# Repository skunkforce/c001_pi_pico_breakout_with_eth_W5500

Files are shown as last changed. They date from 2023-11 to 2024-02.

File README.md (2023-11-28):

# edgy_board number c001
This design is part of the [edgy board project](https://github.com/skunkforce/edgy_boards).

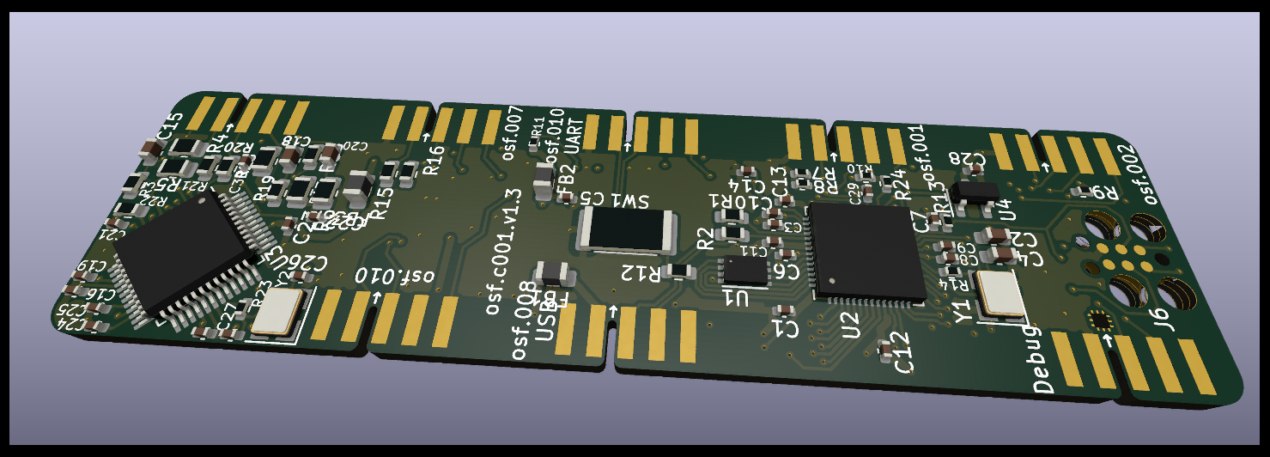
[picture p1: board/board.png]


This design is a composition of edgies.
```mermaid
graph LR
    b018(b018 RP2040)-- SPI -->b078(b078 Ethernet MAC+PHY)
    b018--> b096(b096 MAC ID)

```
# getting started
This repository uses submodules. After cloning use the command 

```$ git submodule update --init --recursive```

to pull the submodules before opening the project with kicad. 

# Tests
Tests can be found in [TESTS.md](TESTS.md)

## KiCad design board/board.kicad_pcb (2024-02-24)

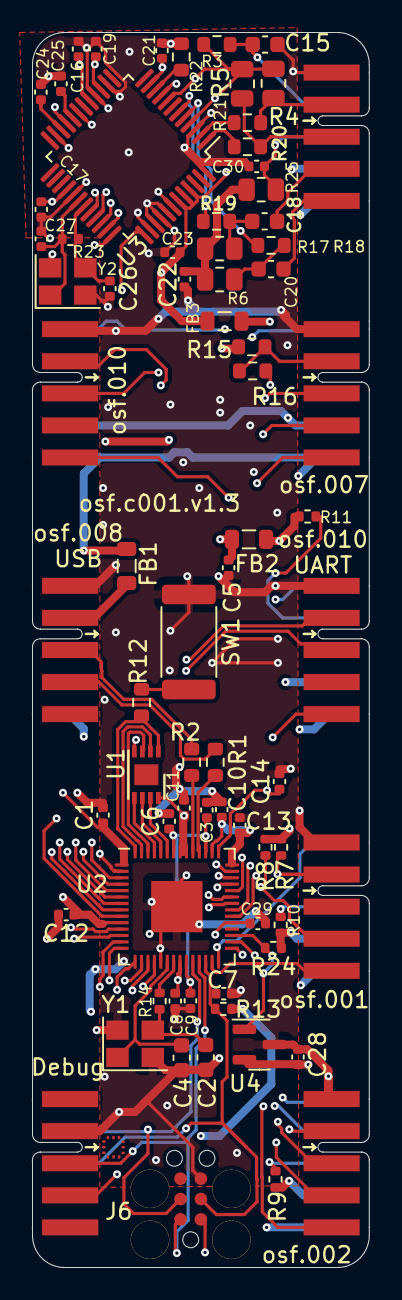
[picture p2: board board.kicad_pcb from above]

Board: 4 copper layers, 21.0 x 77.0 mm, 75 parts (1 on the bottom side), 76 nets.

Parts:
C1, C3, C5, C6, C8, C10, C11, C12, C16, C17, C19, C21, C23, C28, C29, C30: 100nF; C_0402_1005Metric
C2, C4: 12pF; C_0603_1608Metric
C7: 1uF; C_0402_1005Metric
C9, C13, C14: 2.2uF; C_0402_1005Metric
C15: 22nF; C_0603_1608Metric
C18, C20: 6.8nF; C_0603_1608Metric
C22, C24: 10nF; C_0402_1005Metric
C25: 4.7uF; C_0402_1005Metric
C26, C27: 18pF; C_0402_1005Metric
FB1: Ferrite_Bead_Small; L_0805_2012Metric
FB2, FB3: FerriteBead_Small; L_0805_2012Metric
J1: UART; on_edge_2x05_device
J2: 008_USB; on_edge_2x05_device
J3: DebugEdge_02x05; debug_edge_2x05_device
J4: 019_100BASE-T_with_CT; on_edge_2x05_host
J5: ADC_2x3; on_edge_2x05_host
J6: SWD_6_Pol_Needle; SWD6pol
J7: SPI_2x3; on_edge_2x05_host
J8: I2C_2x2; on_edge_2x05_host
J9: UART_2x2; on_edge_2x05_host
LOGO1: Logo_Open_Hardware_Small; OSHW-Symbol_6.7x6mm_SilkScreen
R1, R2: 27R; R_0603_1608Metric
R3: 10R; R_0603_1608Metric
R4, R5, R6, R17: 49.9R; R_0805_2012Metric
R7, R8, R24: 2k; R_0402_1005Metric
R9, R10, R11, R13: 10k; R_0402_1005Metric
R12: 1k; R_0603_1608Metric
R14: 1k; R_0402_1005Metric
R15: 200R; R_0603_1608Metric
R16: 1R; R_0603_1608Metric
R18, R19, R20, R21: 3.3R; R_0603_1608Metric
R22: 12.4k; R_0603_1608Metric
R23: 1M; R_0402_1005Metric
R25: d.n.p; R_0805_2012Metric
SW1: PTS636 SK25J SMTR LFS; R_2512_6332Metric
U1: W25Q16JVUXIQ; DFN-8-1EP_3x2mm_P0.5mm_EP1.3x1.5mm
U2: RP2040; QFN-56-1EP_7x7mm_P0.4mm_EP3.2x3.2mm
U3: W5500; LQFP-48_7x7mm_P0.5mm
U4: 11AA02E48; SOT-23
Y1: 12MhZ; Crystal_SMD_Abracon_ABM8G-4Pin_3.2x2.5mm
Y2: 25MhZ; Crystal_SMD_Abracon_ABM8G-4Pin_3.2x2.5mm

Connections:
+3.3V: C28.1, FB2.1, FB3.2, J1.9 (3.3V), J4.9 (3.3V), J5.9 (3.3V), J7.9 (3.3V), J8.9 (3.3V), J9.9 (3.3V), R7.1, R8.1, R9.1, R10.1, R11.1, R24.1, U4.2 (VCC)
+5V: FB1.1, J1.10 (5V), J2.10 (5V), J4.10 (5V), J5.10 (5V), J7.10 (5V), J8.10 (5V), J9.10 (5V)
/ADC0: J5.3 (ADC0), U2.38 (GPIO26_ADC0)
/ADC1: J5.4 (ADC1), U2.39 (GPIO27_ADC1)
/ADC2: J5.5 (ADC2), U2.40 (GPIO28_ADC2)
/ADC3: J5.6 (ADC3), U2.41 (GPIO29_ADC3)
/ADC_VREF: J5.2 (VREF), R15.2, R16.1
/DM: R1.2, U2.46 (USB_DM)
/DP: R2.2, U2.47 (USB_DP)
/GPIO14: J7.5 (INT), U2.17 (GPIO14)
/GPIO15: J7.7 (status), U2.18 (GPIO15)
/GPIO16: J8.5 (INT), U2.27 (GPIO16)
/GPIO17: J8.6 (CS/EN), U2.28 (GPIO17)
/GPIO22: J9.6 (CS/EN), U2.34 (GPIO22)
/GPIO23: J9.5 (INT), U2.35 (GPIO23)
/GPIO24: J1.5 (INT), U2.36 (GPIO24)
/GPIO25: J1.6 (CS/EN), U2.37 (GPIO25)
/I2C1_SCL: J8.4 (SCL), R8.2, U2.30 (GPIO19)
/I2C1_SDA: J8.2 (SDA), R7.2, U2.29 (GPIO18)
/SPI1_RX: J7.3 (MISO), U2.15 (GPIO12)
/SPI1_SCK: J7.4 (SCLK), U2.13 (GPIO10)
/SPI1_TX: J7.2 (MOSI), U2.14 (GPIO11)
/UART0_RX: J1.2 (TX), U2.3 (GPIO1)
/UART0_TX: J1.3 (RX), U2.2 (GPIO0)
/UART1_RX: J9.3 (RX), U2.12 (GPIO9)
/UART1_TX: J9.2 (TX), U2.11 (GPIO8)
/controller/1V2O: C24.2, U3.22 (1V2O)
/controller/CT1: C15.1, J4.7 (CT1), R3.1
/controller/CT2: C30.1, J4.8 (CT2), R25.1
/controller/RXN: C20.1, J4.5 (TD2-)
/controller/RXP: C18.1, J4.4 (TD2+)
/controller/TXN: J4.3 (TD1-), R5.1, R20.1
/controller/TXP: J4.2 (TD1+), R4.1, R21.1
/controller/VDD: C16.1, C17.1, C19.1, C21.1, C23.1, FB3.1, R3.2, R4.2, R5.2, U3.4 (AVDD), U3.8 (AVDD), U3.11 (AVDD), U3.15 (AVDD), U3.17 (AVDD), U3.21 (AVDD), U3.28 (VDD), U3.43 (PMODE2), U3.44 (PMODE1), U3.45 (PMODE0)
/controller/XCAP: C25.1, U3.20 (TOCAP)
/controller/XI: C27.1, R23.1, U3.30 (XI), Y2.1
/controller/XO: C26.1, R23.2, U3.31 (XO), Y2.3
/controller/XRES: R22.1, U3.10 (EXRES)
/mac/IO: R24.2, U2.31 (GPIO20), U4.1 (SCIO)
/rp2040/GPIO6: U2.8 (GPIO6), U3.36 (INT)
/rp2040/GPIO7: U2.9 (GPIO7), U3.37 (RESET)
/rp2040/QPI_SS: R12.2, U1.1 (~CS), U2.56 (QSPI_SS)
/rp2040/QSPI_CLK: U1.6 (CLK), U2.52 (QSPI_SCLK)
/rp2040/RUN: C7.1, J3.4 (~RESET), J6.3 (nRes), R13.2, U2.26 (RUN)
/rp2040/SPI0_RX: U2.6 (GPIO4), U3.34 (MISO)
/rp2040/SPI0_SCK: U2.4 (GPIO2), U3.33 (SCLK)
/rp2040/SPI0_TX: U2.5 (GPIO3), U3.35 (MOSI)
/rp2040/SWCLK: J3.3 (SWDCLK/TCLK), J6.4 (SWCLK), U2.24 (SWCLK)
/rp2040/SWD: J3.2 (SWDIO/TMS), J6.2 (SWDIO), U2.25 (SWD)
/rp2040/~SPI0_CS: U2.7 (GPIO5), U3.32 (CS)
/uC3.3V: C1.1, C5.1, C8.1, C10.1, C11.1, C12.1, C13.1, C29.1, FB2.2, J3.5 (Vref), J6.1 (VTref), R13.1, R15.1, U1.8 (VCC), U2.1 (IOVDD), U2.10 (IOVDD), U2.22 (IOVDD), U2.33 (IOVDD), U2.42 (IOVDD), U2.44 (VREG_IN), U2.48 (USB_VDD), U2.49 (IOVDD)
/~SPI1_CS: J7.6 (CS), U2.16 (GPIO13)
GND: C1.2, C2.2, C3.2, C4.2, C5.2, C6.2, C7.2, C8.2, C9.2, C10.2, C11.2, C12.2, C13.2, C14.2, C15.2, C16.2, C17.2, C19.2, C21.2, C22.2, C23.2, C24.1, C25.2, C26.2, C27.2, C28.2, C29.2, C30.2, J1.1 (GND), J2.1 (GND), J3.1 (GND), J4.1 (GND), J4.6 (GND), J5.1 (GND), J6.5 (GND), J7.1 (GND), J8.1 (GND), J9.1 (GND), R22.2, SW1.1, U1.4 (GND), U2.19 (TESTEN), U2.57 (GND), U3.3 (AGND), U3.9 (AGND), U3.14 (AGND), U3.16 (AGND), U3.19 (AGND), U3.23 (RSVD), U3.29 (GND), U3.38 (RSVD), U3.39 (RSVD), U3.40 (RSVD), U3.41 (RSVD), U3.42 (RSVD), U3.48 (AGND), U4.3 (GND), Y1.2, Y1.4, Y2.2, Y2.4
unnamed: C2.1, R14.1, Y1.3
unnamed: C18.2, R17.2, R19.1
unnamed: C20.2, R6.2, R18.1
unnamed: C22.1, R6.1, R17.1, R25.2
unnamed: J2.4 (DM), R1.1
unnamed: J2.3 (DP), R2.1
unnamed: FB1.2, J2.2 (VBUS)
unnamed: J7.8 (~RESET), R9.2
unnamed: J8.8 (~RESET), R10.2
unnamed: J9.7 (~RESET), R11.2
unnamed: R12.1, SW1.2
unnamed: U1.5 (DI(IO0)), U2.53 (QSPI_SD0)
unnamed: U1.2 (DO(IO1)), U2.55 (QSPI_SD1)
unnamed: U1.3 (IO2), U2.54 (QSPI_SD2)
unnamed: U1.7 (IO3), U2.51 (QSPI_SD3)
unnamed: C14.1, R16.2, U2.43 (ADC_AVDD)
unnamed: C3.1, C6.1, C9.1, U2.23 (DVDD), U2.45 (VREG_VOUT), U2.50 (DVDD)
unnamed: C4.1, U2.20 (XIN), Y1.1
unnamed: R14.2, U2.21 (XOUT)
unnamed: R18.2, U3.5 (RXIN)
unnamed: R19.2, U3.6 (RXIP)
unnamed: R20.2, U3.1 (TXON)
unnamed: R21.2, U3.2 (TXOP)

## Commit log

2023-02-28 updated schemetic and layout
    [board.kicad_pcb, board.kicad_sch, controller.kicad_sch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]
2023-02-28 updated board picture
2023-02-28 added needle addapter
    [board.kicad_pcb, board.kicad_sch, mac.kicad_sch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]
2023-03-01 added power planes
    [board.kicad_pcb]
2023-03-01 improved power integrity
    [board.kicad_pcb, board.kicad_sch, rp2040.kicad_sch]
2023-03-01 improved board emc
    [board.kicad_pcb]
2023-03-03 improved EMC
    [board.kicad_pcb]
2023-03-04 updated put_on_edge connectors
    [board.kicad_pcb, board.kicad_sch]
2023-05-09 updated to use v1.1 of b078 to work with shorted center tap magjacks
    [board.kicad_pcb, board.kicad_sch, controller.kicad_sch]
2023-11-28 added boot select button and standard (small) flash
    [board.kicad_pcb, board.kicad_sch, controller.kicad_sch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]
2023-12-29 fixed I2C pinning defect
    [board.kicad_pcb, board.kicad_sch]
2024-01-05 moved all components to top layer
    [board.kicad_pcb, board.kicad_sch, controller.kicad_sch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]
2024-02-24 added lcsc part numbers
    [board.kicad_pcb, board.kicad_sch, controller.kicad_sch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]
